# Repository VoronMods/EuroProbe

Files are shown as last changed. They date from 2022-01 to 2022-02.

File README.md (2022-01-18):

# EuroProbe

## Crossover between Euclid and Klicky, but not sure if I will go on with it and adopt Euclid PCB instead.
To some degree, compatible with both mounting and dock systems.

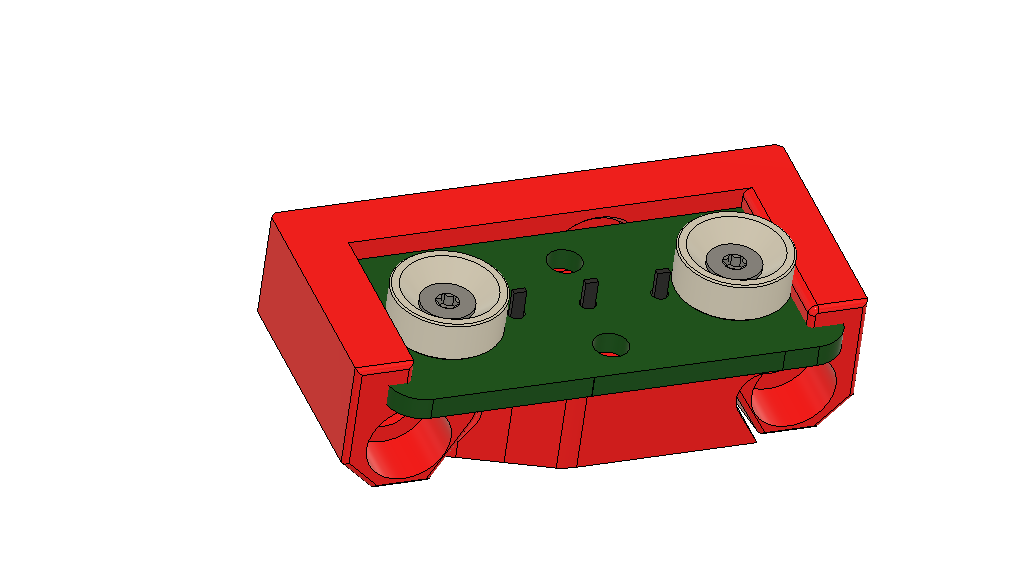
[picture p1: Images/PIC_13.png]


## I need to redesign the Omron adapters and move the probe mounting holes 1mm to make space for the JST connector, now you have to cut one of the JST walls.
## if moved 1mm to the right, the switch button won't be centered anymore, not a problem but still. You will have two versions if you don't want to cut the JST wall, It's irrelevant for DuPont connector.

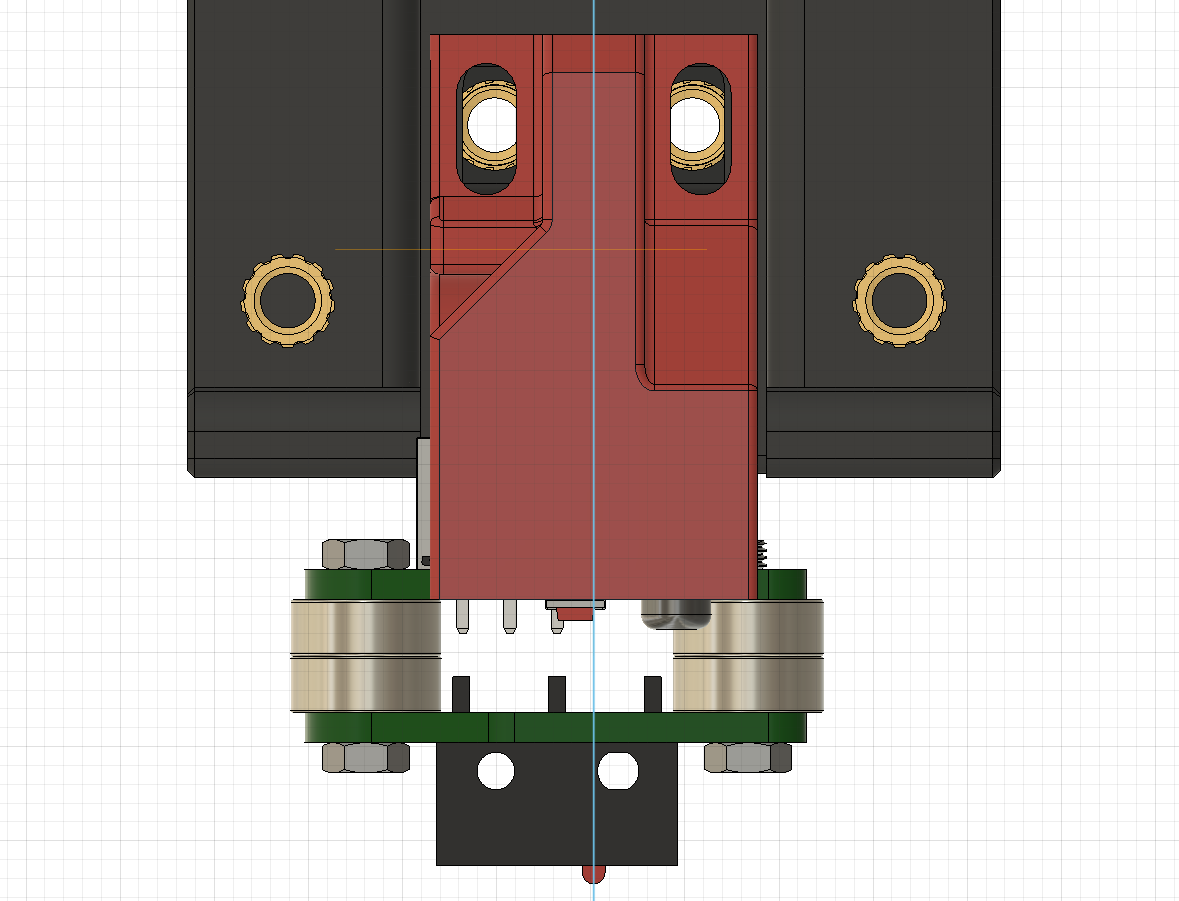
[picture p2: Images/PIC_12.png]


## Klipper plugin for a self calibrating Z offset, useful if you have few spring steel sheets with different thickness, this plugin will adjust every time to your surface/build plate automatically, no need for manual Z offset https://github.com/protoloft/klipper_z_calibration

This is the Euclid Probe moded for EU as the original magnets and hardware are non standard and not obtainable in EU, just in US.

Changed are the magnets to 8mm South and North pole.

All STL's have correct print orientation and no need for supports. 
Trident_8mm_ProbeDock.stl needs supports, will change it later and add build in support.

### Mounting the top PCB to Afterburner adapter:
- 2x M2x10mm BHCS self taping 

or

- 2x M2x8 and 2xM2 heat inserts (5mm OD and 4.5mm lenght)

or

- 2x [M3 BHCS with modded head to 4.6 OD](https://github.com/VoronMods/V1/blob/main/Euro_Probe/Images/PIC_5.png), self taping or heat inserts (all adapters in STL)

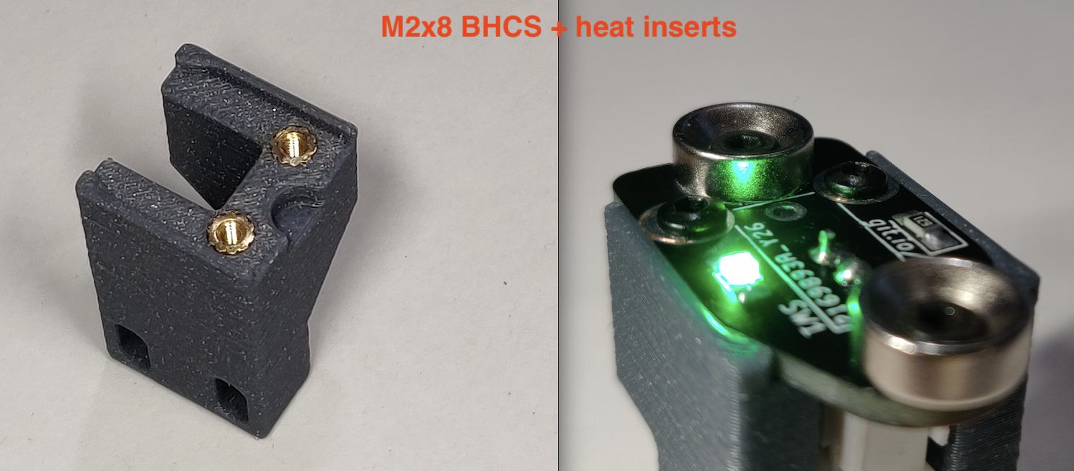
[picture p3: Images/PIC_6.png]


### Installing magnets:
- 4x M2x5mm FHCS 
- 4x M2 nuts, you can also just screw direct in to the PCB. There is enough friction to hold it secure as PCS is glass fiber.

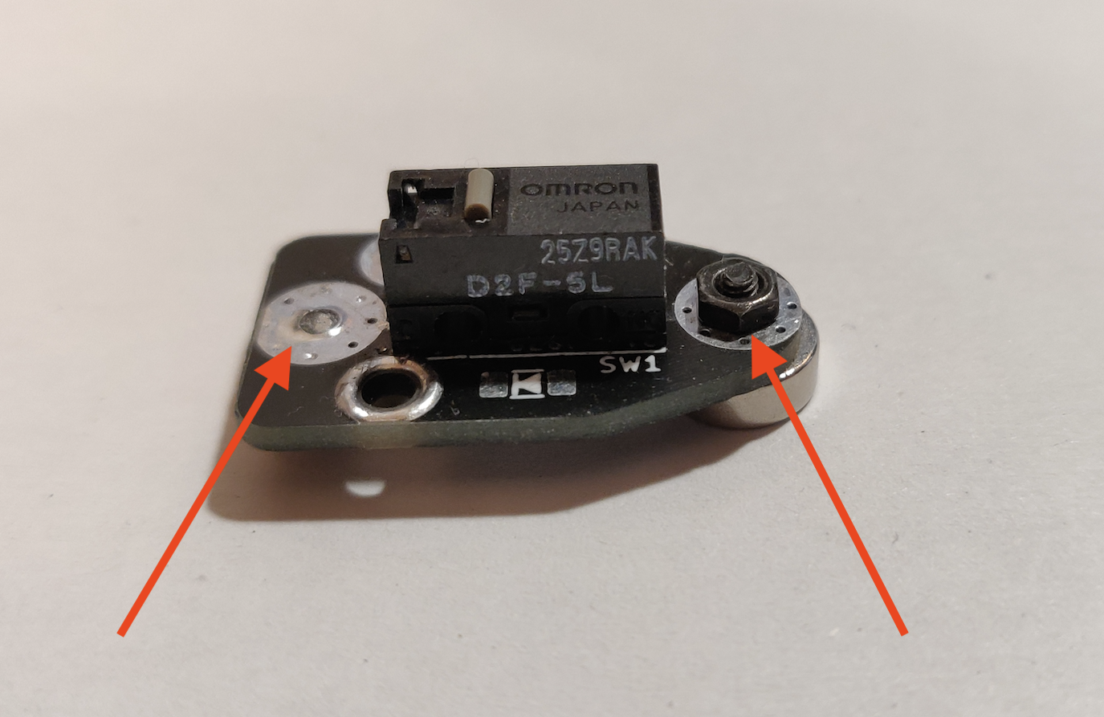
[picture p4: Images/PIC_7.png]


### Added dock for the Klicky mount. Not tested yet.
For the mount STL in picture, you don't need the red spacer.
With the other Klicky mounts, there is not enough clearance, therefore you need to use a 5 mm spacer (red in the pic), or 3 mm spacer for the side mount.

To install the dock you will need:

- 2x M3x8-10mm

- or
 
- 2x M3x16-18mm if you use the 5 mm spacer

- or
 
- 2x M3x12-16mm if you use the 3 mm spacer

Klicky repo:
https://github.com/jlas1/Klicky-Probe

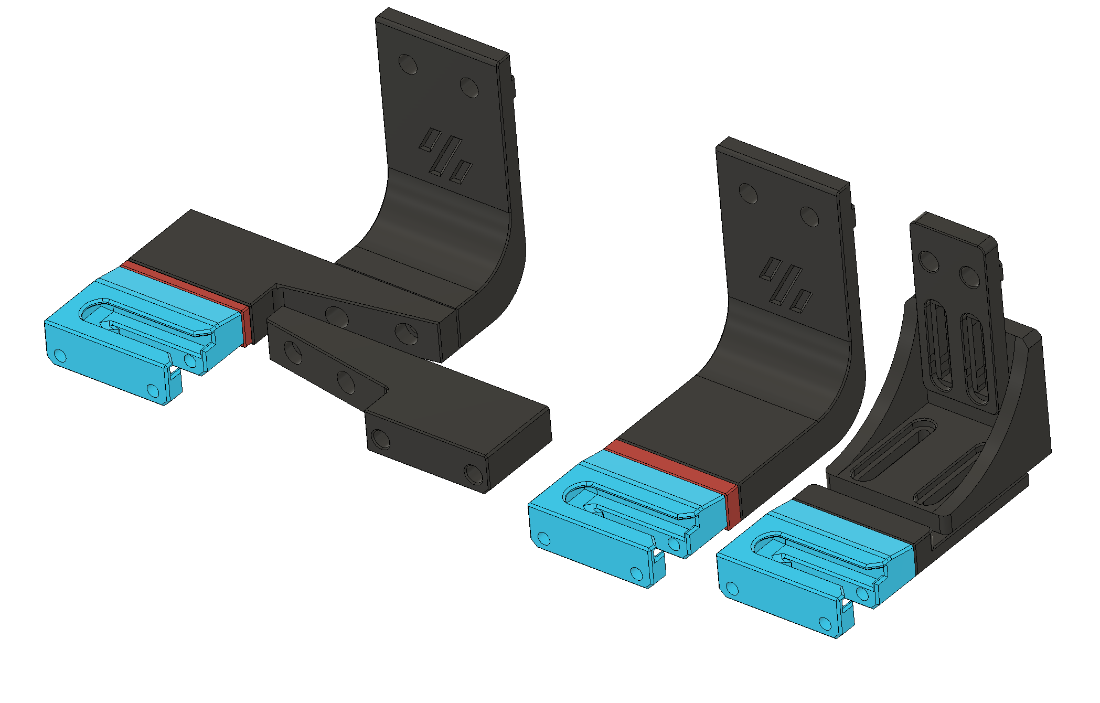
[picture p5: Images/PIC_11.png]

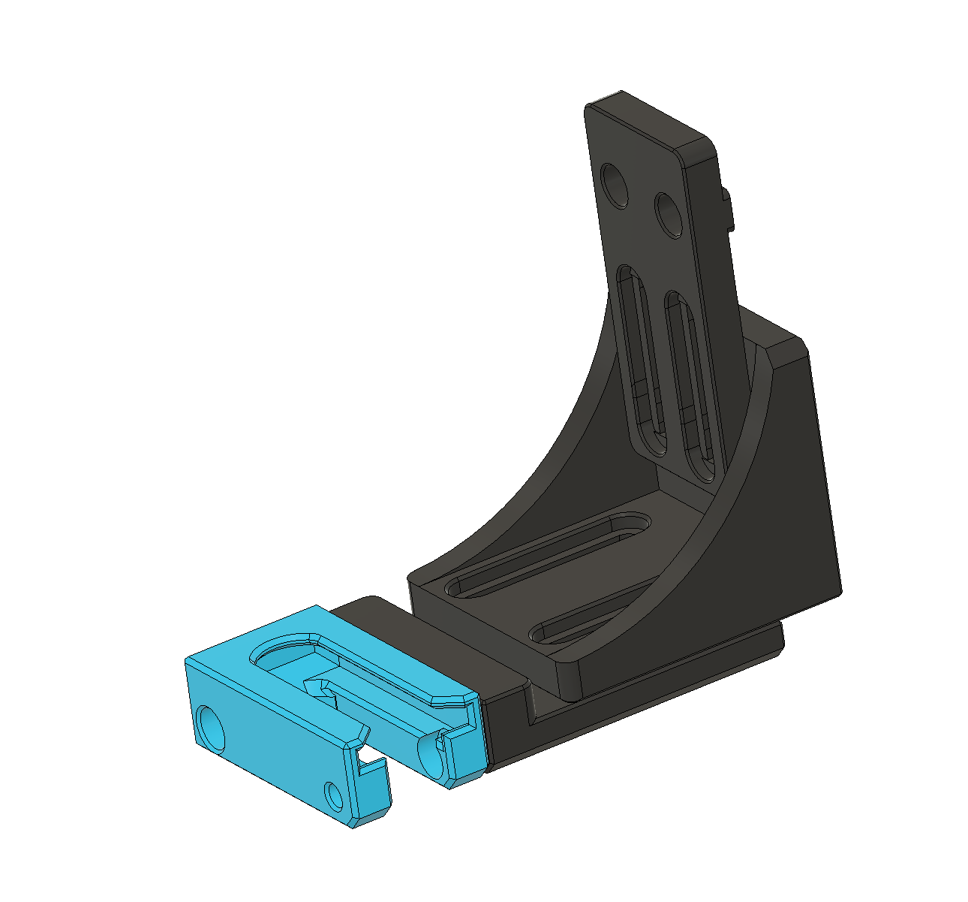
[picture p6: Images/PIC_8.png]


If you want to integrate the probe in to the new carriage, let me know. I will upload after is done.

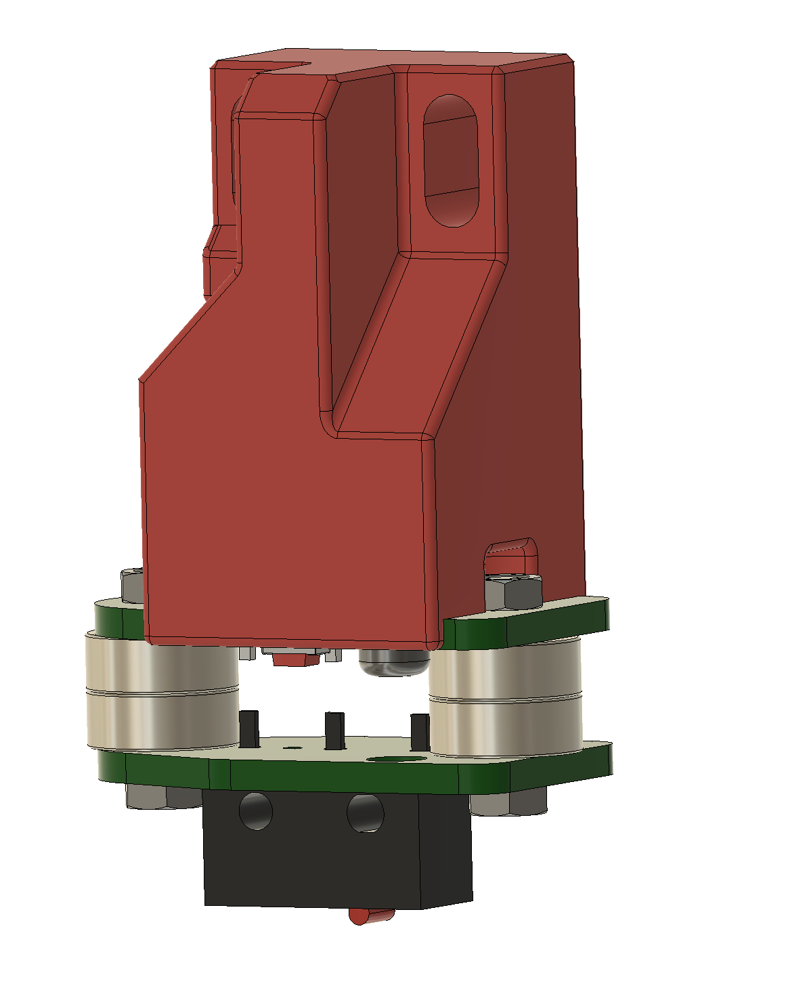
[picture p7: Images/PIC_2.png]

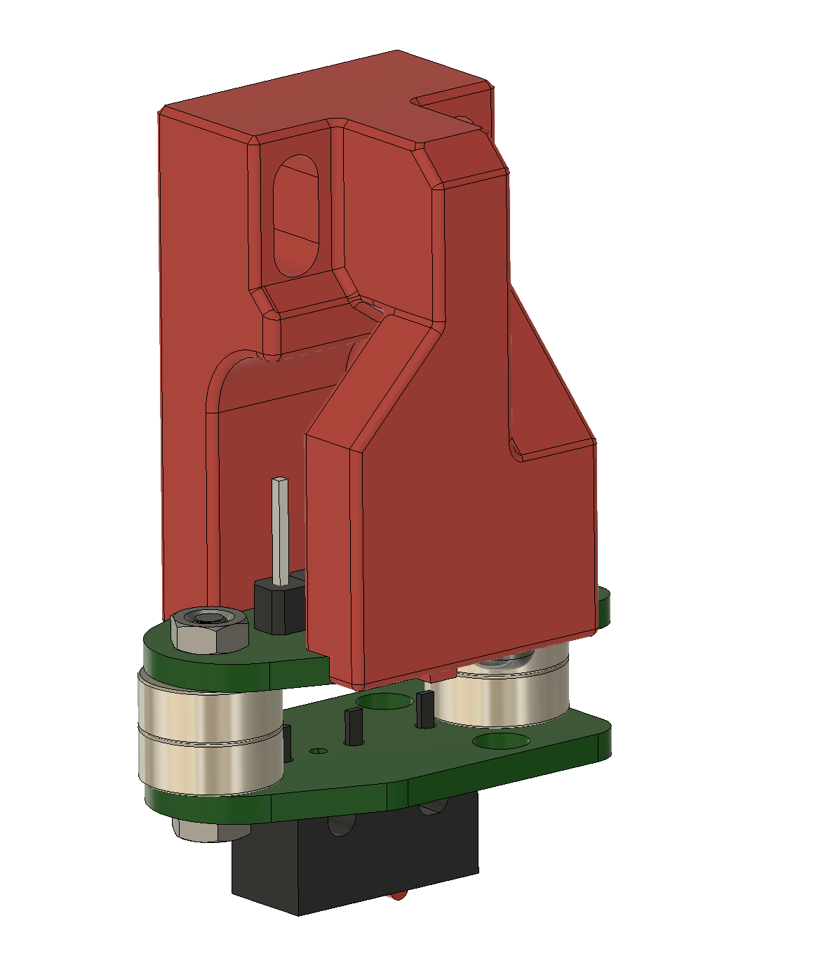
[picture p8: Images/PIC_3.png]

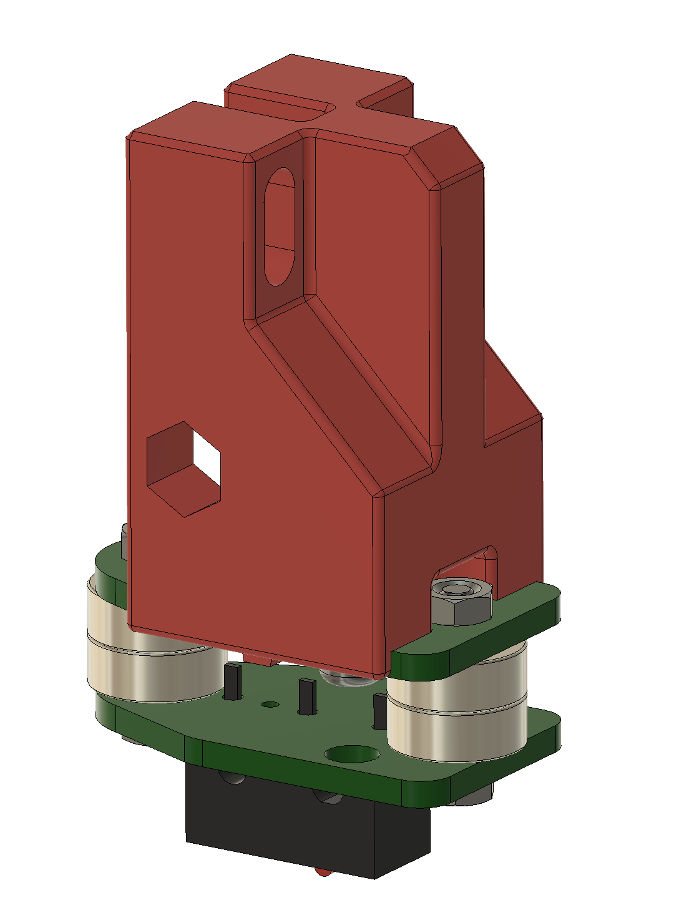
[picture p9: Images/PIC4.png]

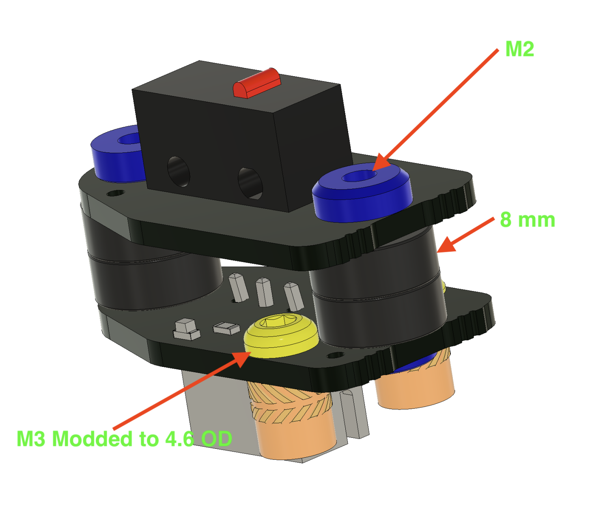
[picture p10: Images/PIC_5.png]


Omron Adapter for Afterburner/Stealthburner designed from scratch to fit the 8mm magnets and other changes.

Original is here
https://github.com/nionio6915/Euclid_Probe/

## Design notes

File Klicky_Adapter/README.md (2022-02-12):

# Klicky Adapter for Euclid Probe

This is just a try to adopt the Klicky Dock mounts for Euclid.
I did not test it on a printer, just a CAD try.

The STL's have correct print orientation, you still need to use selected support, as I did not include sacrificial walls. 

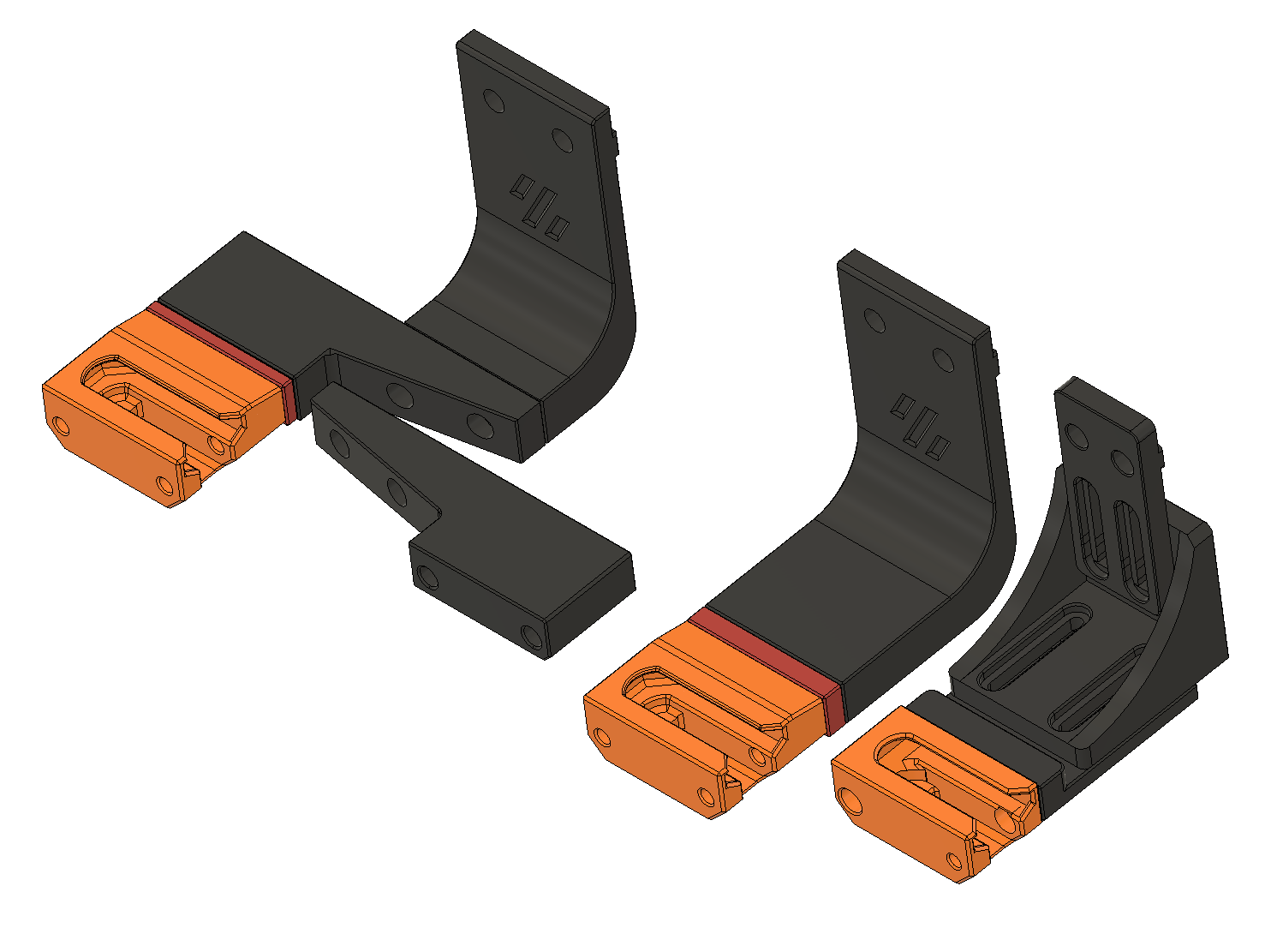
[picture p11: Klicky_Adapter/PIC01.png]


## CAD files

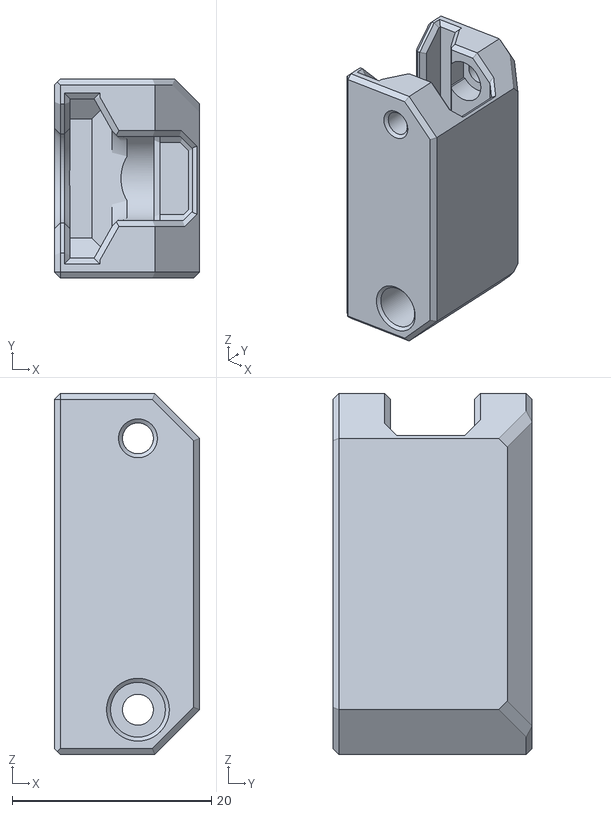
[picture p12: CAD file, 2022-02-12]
Klicky_Adapter/STL/VariableProbeDock.stl
14.6 x 20.0 x 36.3

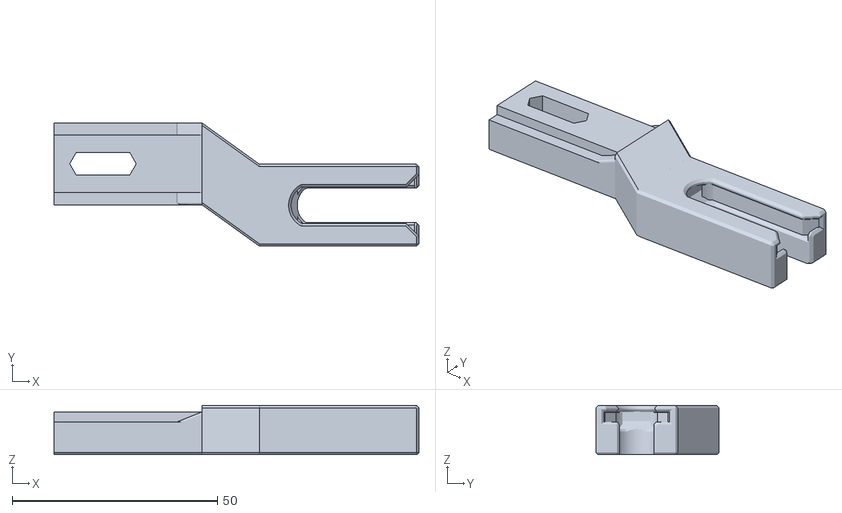
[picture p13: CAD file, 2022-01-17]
STL/VoronGantryMount2_dock_with_support.stl
89.0 x 30.1 x 12.0

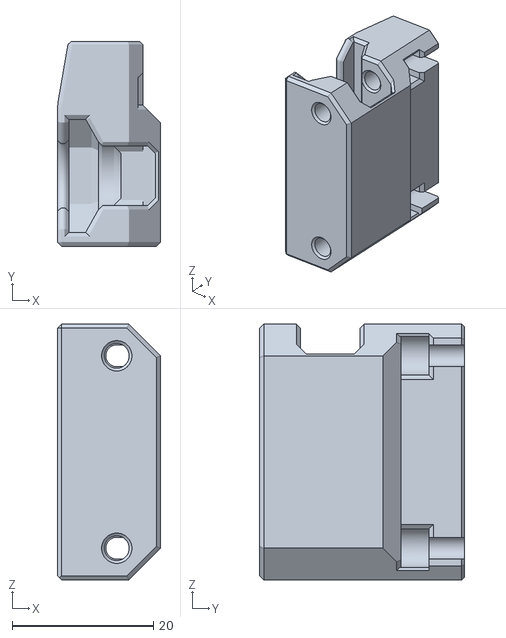
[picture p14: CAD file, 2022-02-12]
Klicky_Adapter/STL/KlickyAdapterDock_v1.stl
14.6 x 29.0 x 36.3

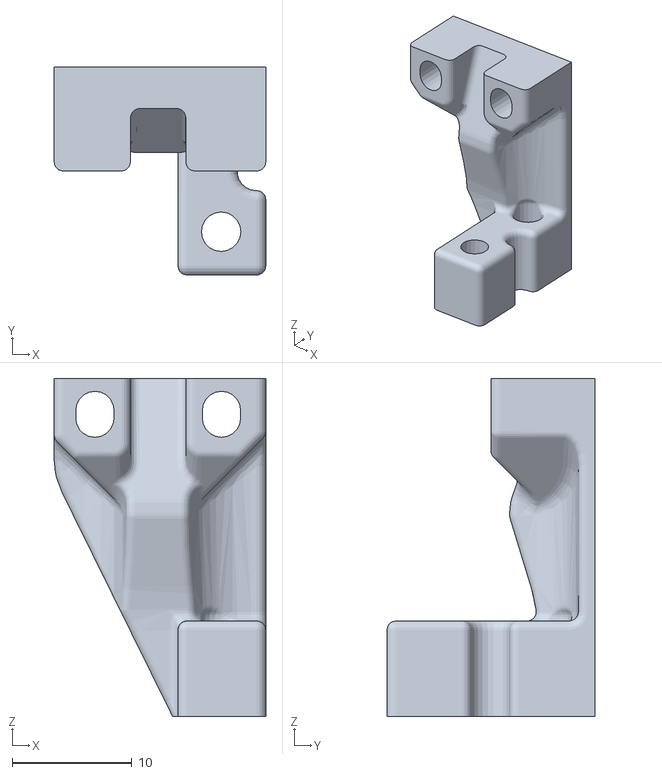
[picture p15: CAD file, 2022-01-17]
STL/slim_mount.stl
17.7 x 17.4 x 28.3

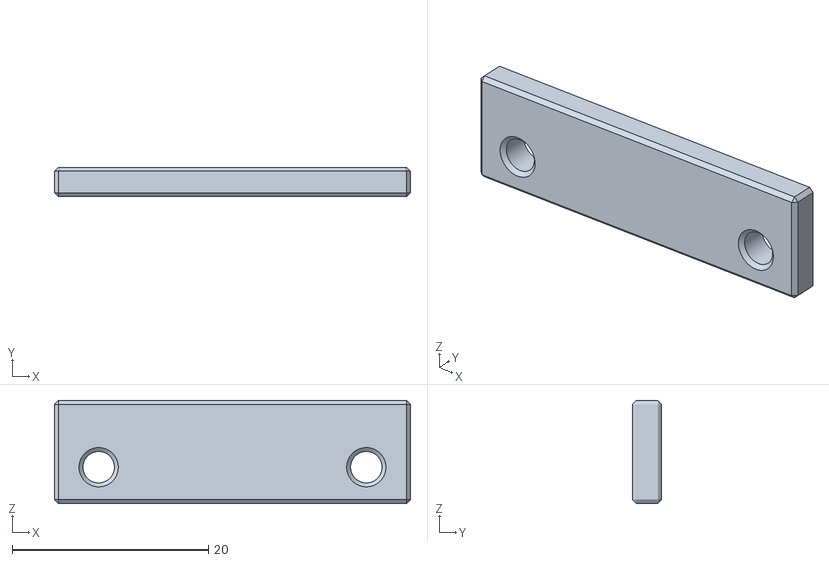
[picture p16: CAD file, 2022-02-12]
Klicky_Adapter/STL/3mm Spacer.stl
36.3 x 3.00 x 10.5

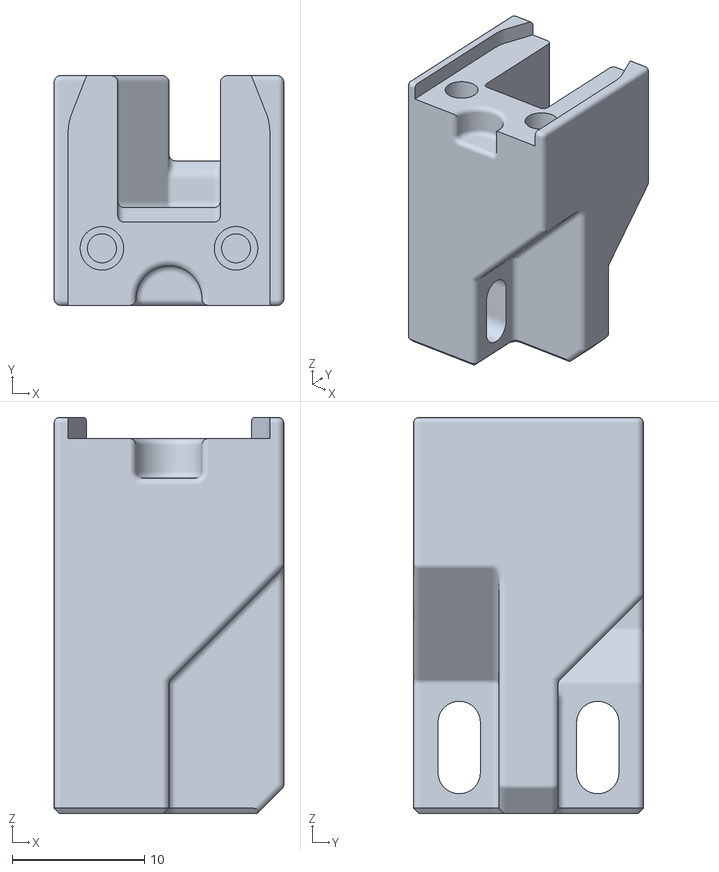
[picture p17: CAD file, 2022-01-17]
STL/Omron_M2_Heatinsert(3.3).stl
17.4 x 17.4 x 30.0

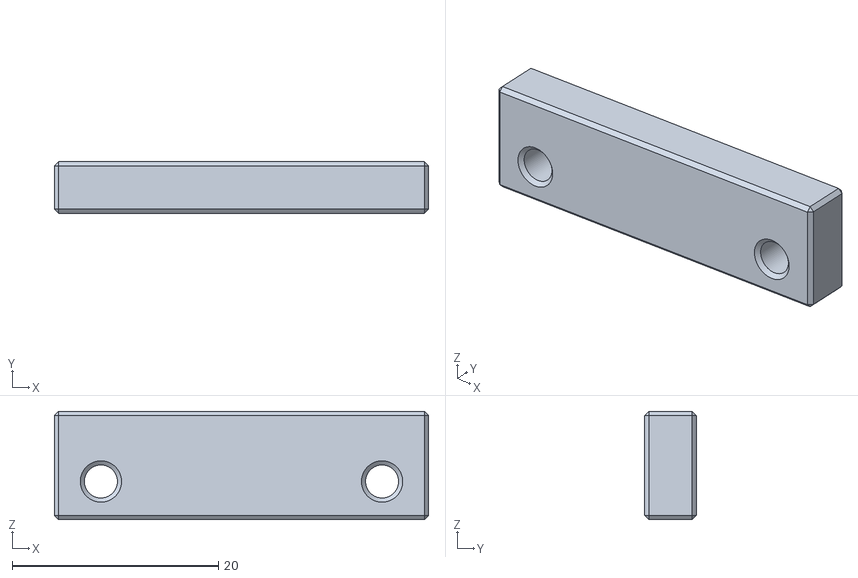
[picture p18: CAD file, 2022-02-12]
Klicky_Adapter/STL/5mm Spacer.stl
36.3 x 5.00 x 10.5

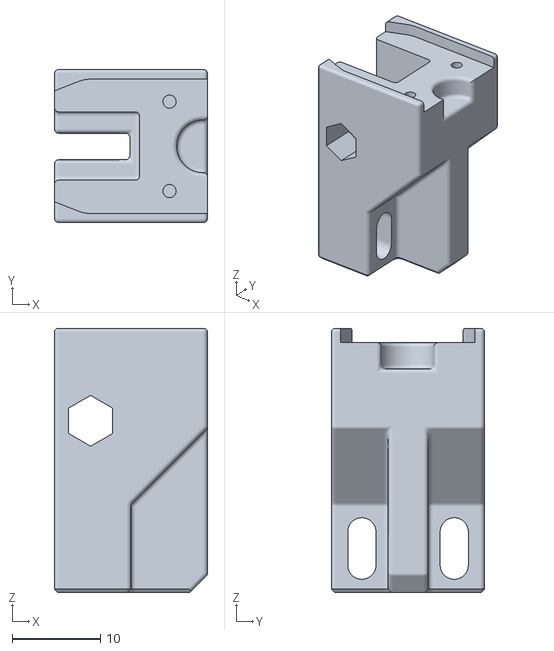
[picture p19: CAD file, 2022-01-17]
STL/Omron90_M2 Tap(1.5).stl
17.4 x 17.4 x 30.0

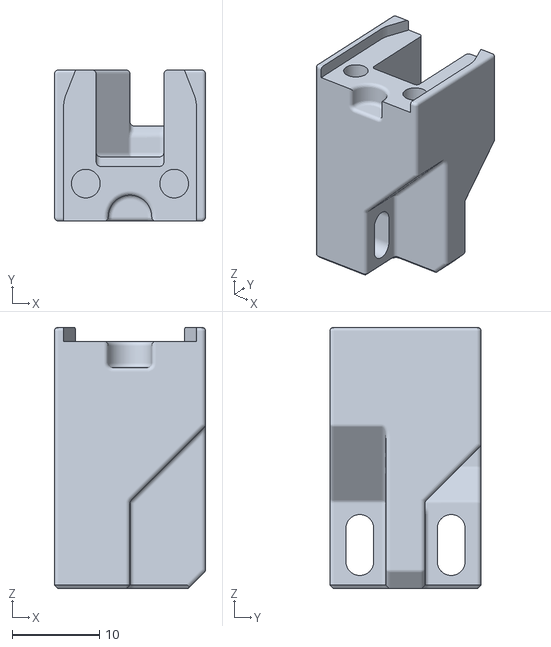
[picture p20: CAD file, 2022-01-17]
STL/Omron_M3_Tap(2.5).stl
17.4 x 17.4 x 30.0

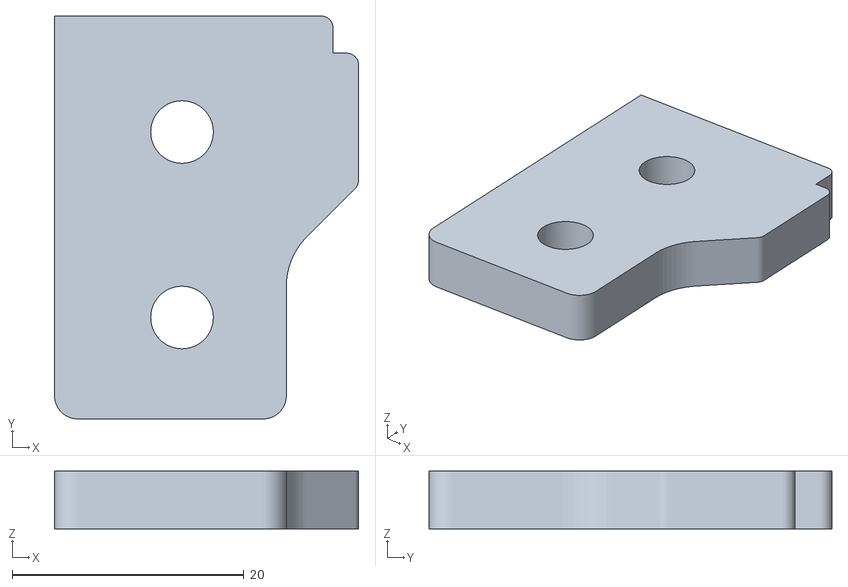
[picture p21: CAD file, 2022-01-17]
STL/5mm Spacer.stl
26.2 x 34.8 x 5.00

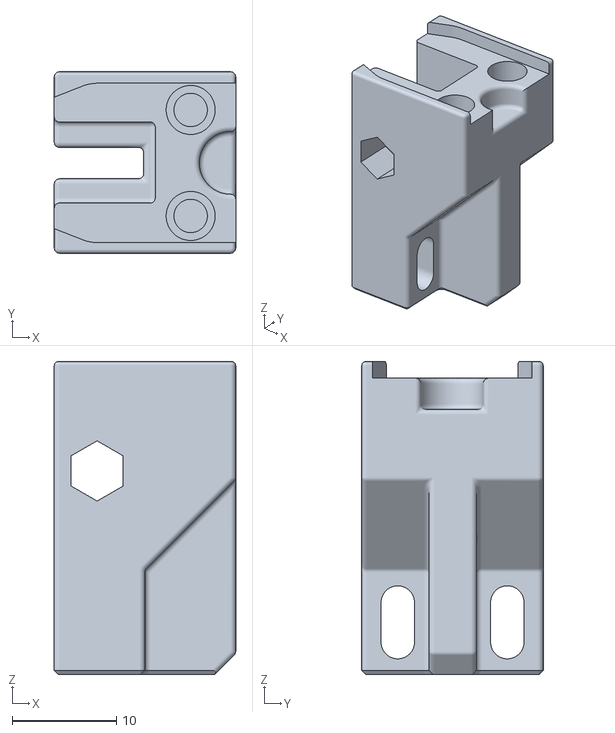
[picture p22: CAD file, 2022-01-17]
STL/Omron90_M3_Heatinsert(4.7).stl
17.4 x 17.4 x 30.0

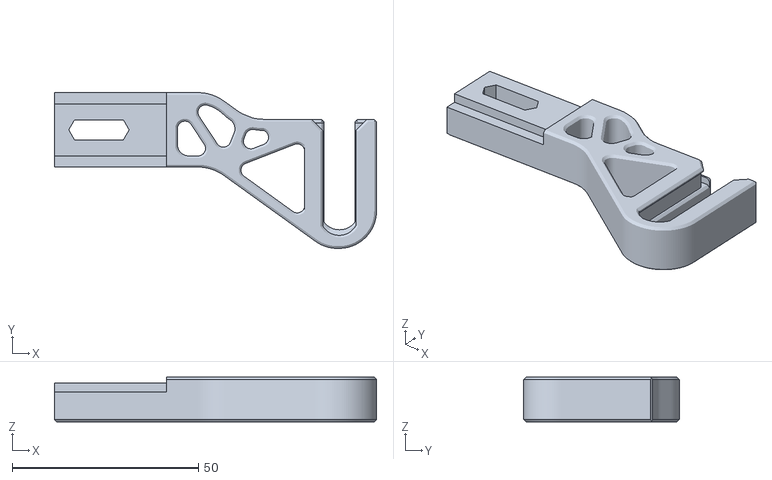
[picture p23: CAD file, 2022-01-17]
STL/VoronGantryMount2NativeCarriage_Dock.stl
86.5 x 41.8 x 12.0

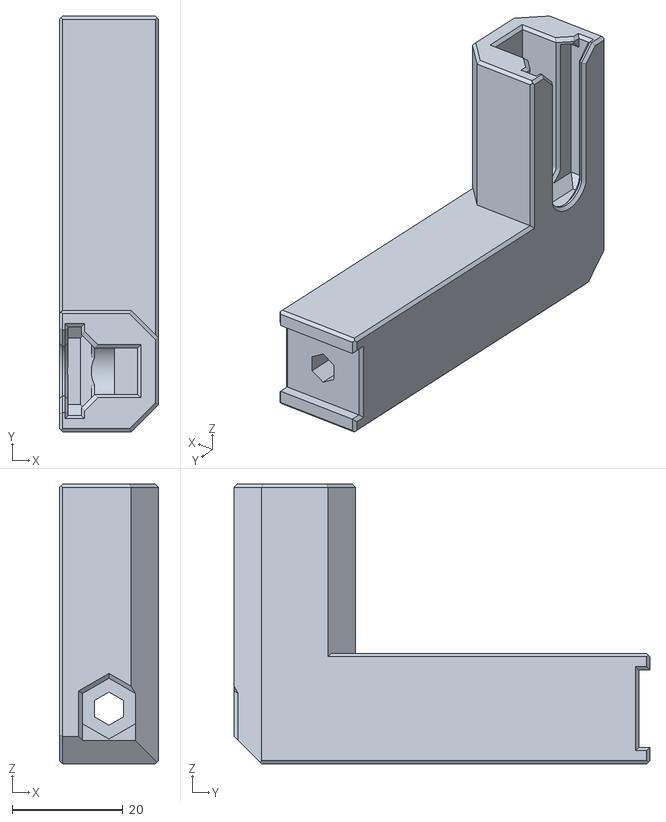
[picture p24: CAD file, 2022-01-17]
STL/Trident_8mm_ProbeDock_V2.stl
18.0 x 75.3 x 50.6

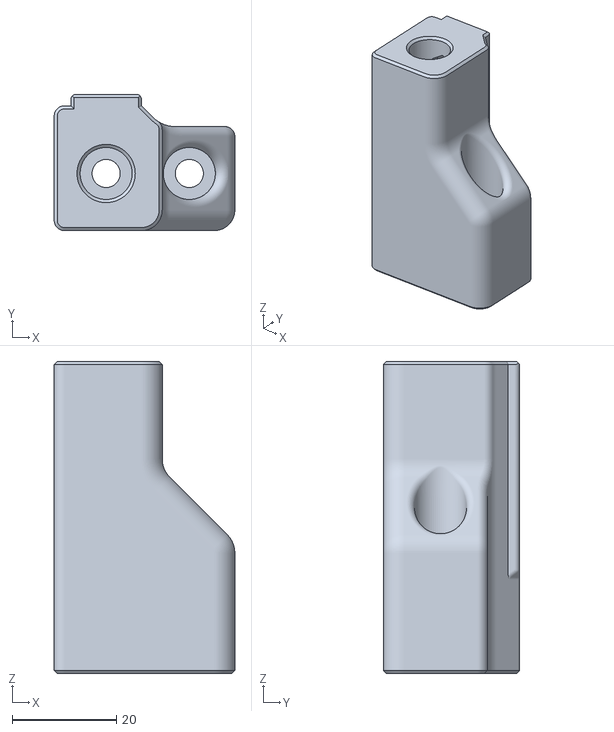
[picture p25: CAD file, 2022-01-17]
STL/Trident_Top_Mount.stl
34.8 x 26.2 x 60.0

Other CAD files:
STL/Omron90_M3 Tap(2.5).stl
STL/3mm_Spacer.stl
STL/Omron90_M2_Heatinsert(3.3).stl
STL/Omron_M3_Heatinsert(4.7).stl
STL/5mm_Spacer.stl
STL/Omron_M2 Tap(1.5).stl
STL/ProbeDock_for_Klicky_mount.stl
STL/Voron2.4BedMount_Dock.stl
STL/VoronGantryMount2_dock.stl
STL/VoronGantryMount2_mount.stl

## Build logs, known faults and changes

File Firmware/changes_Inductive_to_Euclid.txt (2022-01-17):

From inductive to Euclid:

Changes in printer.cfg 

Add:
[include euclid.cfg]

[force_move]
enable_force_move: true

Octopus: after the swap Inductive for Euclid endstop status is Triggered, you need to change to ^PG15 (original PG15)

##################
# 	Probe
##################
[probe]
pin: ^PG15

x_offset: 0
y_offset: 22.5
z_offset: 8.0 #0 for Inductive Probe
speed: 5 #30.0 #20.0 for Inductive Probe
samples: 2 #1 for Inductive Probe
samples_result: average
sample_retract_dist: 10.0 #original 3.0 with inductive probe
samples_tolerance: 0.0075 #0.05 was for Inductive Probe
samples_tolerance_retries: 3

Set z_offset: to 8mm (it is the distance from the tip of your nozzle to the tip of the moron switch)

[z_tilt]
#only changed field here

speed: 150 #original 200
horizontal_move_z: 10 #orignal 20 with inductive probe
retries: 5
retry_tolerance: 0.007

Add to bed_mesh if you bet error in hightmap calibration
[bed_mesh]
horizontal_move_z: 20

Changes in euclid.cfg 

For trident, change at the end of the file QUAD_GENTRY_LEVEL to: Z_TILT_ADJUST 
[gcode_macro Z_TILT_ADJUST]
rename_existing:    _Z_TILT_ADJUST
gcode:
  M401                           ; deploy Euclid Probe if needed
  _Z_TILT_ADJUST                       ; check bed level
  M402                           ; dock Euclid Probe

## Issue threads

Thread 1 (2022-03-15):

two Klicky adaptor no longer necessary

jlas1, 2022-03-15:
The sidemount and fixed dock now have the same distance from the extrusion, it should not be necessary any longer to keep the 5 and 3 mm ones.

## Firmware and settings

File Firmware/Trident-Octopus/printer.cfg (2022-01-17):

# This file contains common pin mappings for the BigTreeTech Octopus V1.
# To use this config, the firmware should be compiled for the STM32F446 with a "32KiB bootloader"
# Enable "extra low-level configuration options" and select the "12MHz crystal" as clock reference

# after running "make", copy the generated "klipper/out/klipper.bin" file to a
# file named "firmware.bin" on an SD card and then restart the OctoPus with that SD card.

# See docs/Config_Reference.md for a description of parameters.

## Voron Design Trident 250/300/350mm BigTreeTech OctoPus V1 TMC2209 UART config

## *** THINGS TO CHANGE/CHECK: ***
## MCU paths                            [mcu] section
## Thermistor types                     [extruder] and [heater_bed] sections
## Leadscrew Rotation Distance          [stepper_z], [stepper_z1], [stepper_z2]
## Z Endstop Switch location            [safe_z_home] section
## Z Endstop Switch  offset for Z0      [stepper_z] section
## PID tune                             [extruder] and [heater_bed] sections
## Probe pin                            [probe] section
## Fine tune E steps

## Thermistor Types
##   "EPCOS 100K B57560G104F"
##   "ATC Semitec 104GT-2"
##   "NTC 100K beta 3950"
##   "Honeywell 100K 135-104LAG-J01"
##   "NTC 100K MGB18-104F39050L32"
##   "AD595"
##   "PT100 INA826"
##===================================================================.

#flash FW
#make flash FLASH_DEVICE=/dev/serial/by-id/usb-Klipper_stm32f446xx

[include mainsail.cfg]
#[include flexplate.cfg]


[include euclid.cfg]

[force_move]
enable_force_move: True

[save_variables]
filename: /home/pi/klipper_config/.variables.stb

[virtual_sdcard]
path: ~/gcode_files

[pause_resume]
[display_status]

[mcu]
###Change to device found by "ls -l /dev/serial/by-id/" with just one this MCU connected to Pi
serial: /dev/serial/by-id/usb-Klipper_stm32f446xx_

[printer]
kinematics: corexy
max_velocity: 300
max_accel: 5000
max_z_velocity: 10
max_z_accel: 30
square_corner_velocity: 5.0

[bed_mesh]
speed: 75
horizontal_move_z: 20
mesh_min: 15, 25
mesh_max: 232, 230
probe_count: 5,5
mesh_pps: 2,2
algorithm: bicubic
bicubic_tension: .05

[mcu rpi]
serial: /tmp/klipper_host_mcu

#[adxl345]
#cs_pin: rpi:None

#[resonance_tester]
#accel_chip: adxl345
##accel_per_hz: 100  # default is 75
#probe_points:
#    125,125,20  # an example

[adxl345]
cs_pin: rpi:None

[resonance_tester]
accel_chip: adxl345
#accel_per_hz: 100  # default is 75
probe_points:


#####################################################################
# 	X/Y Stepper Settings
#####################################################################\

##  B Stepper - Left
##  Connected to MOTOR_0
##  Endstop connected to DIAG_0
[stepper_x]
step_pin: PF13
dir_pin: PF12
enable_pin: !PF14
microsteps: 16
rotation_distance: 40
#full_steps_per_rotation: 400
endstop_pin: PG6
position_min: 0

position_endstop: 250
position_max: 250

homing_speed: 100 #Max 100
homing_retract_dist: 5
homing_positive_dir: true

[tmc2209 stepper_x]
uart_pin: PC4
run_current: 0.900
hold_current: 0.550
#sense_resistor: 0.110 #not sure if needed
stealthchop_threshold: 250


##  A Stepper - Right
##  Connected to MOTOR_1
##  Endstop connected to DIAG_1
[stepper_y]
step_pin: PG0
dir_pin: PG1
enable_pin: !PF15
microsteps: 16
rotation_distance: 40
#full_steps_per_rotation: 400
endstop_pin: PG9
position_endstop: 258
position_max: 258
homing_speed: 100  #Max 100
homing_retract_dist: 5
homing_positive_dir: true

[tmc2209 stepper_y]
uart_pin: PD11
run_current: 0.900
hold_current: 0.550
#sense_resistor: 0.110
stealthchop_threshold: 250


#####################################################################
# 	Z Stepper Settings
#####################################################################

##  Z0 Stepper - Front Left (M1)
##  Connected to MOTOR_2
##  Endstop connected to DIAG_2
[stepper_z]
step_pin: PF11
dir_pin: !PG3
enable_pin: !PG5
microsteps: 16
##T8x4 Lead Screws.  One rotation moves the bed 4mm
##Change according to integrated steppers purchased
rotation_distance: 8
#full_steps_per_rotation: 200
endstop_pin: PG10
#  Z-position of nozzle (in mm) to z-endstop trigger point relative to print surface (Z0)
#  (+) value = endstop above Z0, (-) value = endstop below
#  Increasing position_endstop brings nozzle closer to the bed
#  After you run Z_ENDSTOP_CALIBRATE, position_endstop will be stored at the very end of your config
#position_endstop: -0.5
## All builds use same Max Z
position_max: 250
position_max: 250
position_min: -2.5
homing_speed: 5

[tmc2209 stepper_z]
uart_pin: PC6
interpolate: False
run_current: 0.650
hold_current: 0.450
#sense_resistor: 0.110
stealthchop_threshold: 30 # old was 30

##  Z1 Stepper - Rear Center (M2)
##  Connected to MOTOR_3
[stepper_z1]
step_pin: PG4
dir_pin: !PC1
enable_pin: !PA0
microsteps: 16
rotation_distance: 8
#full_steps_per_rotation: 200

[tmc2209 stepper_z1]
uart_pin: PC7
interpolate: False
run_current: 0.650
hold_current: 0.450
#sense_resistor: 0.110
stealthchop_threshold: 30 # old was 30

##  Z2 Stepper - Front Right (M3)
##  Connected to MOTOR_4
[stepper_z2]
step_pin: PF9
dir_pin: !PF10
enable_pin: !PG2
microsteps: 16
rotation_distance: 8
#full_steps_per_rotation: 200

[tmc2209 stepper_z2]
uart_pin: PF2
interpolate: False
run_current: 0.650
hold_current: 0.450
#sense_resistor: 0.110
stealthchop_threshold: 30 # old was 30



#####################################################################
#   Extruder
#####################################################################

#   Connected to MOTOR_6
#   Heater - HE0
#   Thermistor - T0
[extruder]
step_pin: PE2
dir_pin: PE3
enable_pin: !PD4
max_extrude_cross_section: 50
max_extrude_only_distance: 700.00
microsteps: 16
# Tune per individual printer
# Default for Bondtech 5mm Bore Drive Gears
#rotation_distance: 22.6789511
#gear_ratio: 50:17
## Bondtech LGX
rotation_distance:  54.45 #55 #for LGX        #for mini AB  21.855 #21.8553543599825 #21.8851878115 #22.6789511 #22.23        # See calibrating rotation_distance on extruders doc
gear_ratio: 45:14, 37:17 #for LGX      # For Mini Afterburner 50:10
#end LGX
#full_steps_per_rotation: 200
nozzle_diameter: 0.400
filament_diameter: 1.750
pressure_advance: 0.67
pressure_advance_smooth_time: 0.040
heater_pin: PA2
##	Validate the following thermistor type to make sure it is correct
sensor_type: Generic 3950
sensor_pin: PF4
min_extrude_temp: 0
min_temp: 0
max_temp: 300
#control = pid
#pid_kp = 26.213
#pid_ki = 1.304
#pid_kd = 131.721
#Set appropriate once tuning your printer
#pressure_advance: .05
##	Default is 0.040, leave stock
pressure_advance_smooth_time: 0.040

[tmc2209 extruder]
uart_pin: PE1
run_current: 0.5
hold_current: 0.4
#sense_resistor: 0.110
stealthchop_threshold: 30

#####################################################################
# 	Bed Heater
#####################################################################
[heater_bed]
heater_pin: PA1
##  Choose the correct thermistor for your heater
sensor_type: EPCOS 100K B57560G104F
sensor_pin: PF3
##	Adjust Max Power so your heater doesn't warp your bed
max_power: 1
min_temp: 0
max_temp: 120
control: pid
pid_kp: 58.437
pid_ki: 2.347
pid_kd: 363.769

#####################################################################
# 	Probe
#####################################################################
[probe]
##  Inductive Probe
##  This probe is not used for Z height, only Quad Gantry Leveling

# Select the probe port by type:
## For the PROBE port. Will not work with Diode. May need pull-up resistor from signal to 24V.
# pin: ~!PB7
## For the DIAG_7 port. NEEDS BAT85 DIODE! Change to !PG15 if probe is NO.
pin: ^PG15
## For Octopus Pro Probe port; NPN and PNP proximity switch types can be set by jumper
# pin: ^PC5

x_offset: 0
y_offset: 22.5
z_offset: 10 #8.0 #0 for Inductive Probe
speed: 5 #30.0 #20.0 for Inductive Probe
samples: 2 #1 for Inductive Probe
samples_result: average
sample_retract_dist: 5 #original 3.0 with inductive probe
samples_tolerance: 0.0075 #0.05 was for Inductive Probe
samples_tolerance_retries: 3

#####################################################################
# 	Fan Control
#####################################################################

##  Print Cooling Fan - FAN0
[fan]
pin: PA8
max_power: 1.0
kick_start_time: 0.5

##  Hotend Fan - FAN1
[heater_fan hotend_fan]
pin: PE5
max_power: 1.0
kick_start_time: 0.5
heater: extruder
heater_temp: 50.0
##  If you are experiencing back flow, you can reduce fan_speed
#fan_speed: 1.0

#[controller_fan controller_fan]
##  Controller fan - FAN2
#pin: PD12
#kick_start_time: 0.5
#heater: heater_bed

#[heater_fan exhaust_fan]
##  Exhaust fan - FAN3
#pin: PD13
#max_power: 1.0
#shutdown_speed: 0.0
#kick_start_time: 5.0
#heater: heater_bed
#heater_temp: 60
#fan_speed: 1.0

#####################################################################
#   LED Control
#####################################################################
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

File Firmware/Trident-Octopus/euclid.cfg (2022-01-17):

# all sething here are for 250 build

[gcode_macro move_to_dockside]
# this is for gantry mounted dock
# Move to location adjacent to dock X30 Y0
gcode:
  G90                 ; absolute coordinate system
  G0 Z15               ; 
  G0 X40 Y240 F5000         ; Step 2, Dock Adjacent move to X30 Y0

[gcode_macro move_to_dock]
# this is for gantry mounted dock
gcode:
# Move over dock for probe pickup X-30 movement
  G90    ; absolute coordinate system
  G0 Z15
  G0 X40 Y256 F3000         ; Step 3, move to dock over probe at X0 Y0

[gcode_macro move_outof_dock]
# this is for gantry mounted dock
# Location adjacent to dock for exit Y+40 movement 
gcode:
  G90                 ; absolute coordinate system
  # the following line may need a G91 to preceed it depending on overides
  G0 X90 Y256 F5000   
  G0 X90 Y256 Z15 F5000 ; Step 4, mouve out of dock move to X0 Y40 Z15 


# Macro to Deploy Bed Probe
[gcode_macro M401]
gcode:
    G90
    {action_respond_info("Entering M401")}
    error_if_probe_deployed    ; check to make sure that the probe is not already attached
    _M401

[gcode_macro error_if_probe_deployed]
gcode:
    QUERY_PROBE                 ; check probe status
    do_error_if_probe_deployed  ; logic check to verify probe is not already deployed

[gcode_macro do_error_if_probe_deployed]
gcode:
    {% if not printer.probe.last_query %}
      {action_raise_error("Euclid Probe is already deployed - Remove and Return it to the dock")}
    {% endif %}

# Macro to Deploy Bed Probe
#same as Steve's
[gcode_macro _M401]
gcode:
    G90
    {% if printer.probe.last_query %} 
      G0 Z15 F3000         ;  set approach elevation of Z15 to clear probe over bed on fixed gantry machine 
      #                       for moving gantry machine this may need to be adjusted
      G0 X90 Y230          ;  move the carraige to safe position to move from
      move_to_dockside
      G4 P250              ;  wait 1/4 second 
      move_to_dock
      M400                 ;  wait for moves to finish
      G4 P250              ;  pause 1/4 sec for detection
      move_outof_dock
      G0 Z15               ;  move up to clear the probe over the bed of moving gantry or provide clearance for fixed gantry
    error_if_probe_not_deployed
    {% endif %}


[gcode_macro error_if_probe_not_deployed]
gcode:
    QUERY_PROBE
    do_error_if_probe_not_deployed

[gcode_macro do_error_if_probe_not_deployed]
gcode:
    {% if printer.probe.last_query %}
      {action_raise_error("Euclid Probe failed to deploy!")}
    {% endif %}

# Macro to retract Bed Probe
[gcode_macro M402]
gcode:
    G90
    {action_respond_info("Entering M402")}
    error_if_probe_not_deployed
    _M402

# Macro to Stow Bed Leveling Probe
[gcode_macro _M402]
gcode:
    G90
    {% if not printer.probe.last_query %} ; the logic on this needs function check
     G0 Z15 F2400                  ;  set approach elevation of Z15 for fixed gantry system to clear probe over bed
     #                           ;  for moving gantry system this may have to be altered
     G0 X100 Y256 F3000             ;  move to the re-entry staging position
     G0 X70 Y256 F3000             ;  move to a position in front of the dock so simple linear movement into dock 
     G0 X40 Y256 F1000              ;  slowly move into dock 
     M400                        ;  wait for moves to finish
     G4 P250                     ;  forced pause here so motion is definite 90 tavel to swipe
     G0 X40 Y240 F6000             ;  quick swipe off 
     G0 X125 Y125                 ;  move to center of bed                   
     G0 Z20 F500               ;  move up to elevation of Z20
     error_if_probe_deployed
  {% endif %} # Mike: added as it was missing 


# Macro to perform a bed mesh calibration by wrapping it between M401/M402 macros
[gcode_macro BED_MESH_CALIBRATE]
rename_existing:    BED_MESH_CALIBRATE_ORIGINAL
gcode:
  M401                           ; deploy Euclid Probe if needed
  BED_MESH_CALIBRATE_ORIGINAL    ; check bed level
  M402                           ; dock Euclid Probe

# Macro to perform a modified z_tilt  by wrapping it between M401/M402 macros
[gcode_macro Z_TILT_ADJUST]
rename_existing:    _Z_TILT_ADJUST
gcode:
  M401                           ; deploy Euclid Probe if needed
  _Z_TILT_ADJUST                       ; check bed level
  M402                           ; dock Euclid Probe

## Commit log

2022-01-17 added all files
    [3mm_Spacer.stl, 5mm Spacer.stl, 5mm_Spacer.stl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]
2022-01-17 firmware added
    [euclid.cfg, printer.cfg]
